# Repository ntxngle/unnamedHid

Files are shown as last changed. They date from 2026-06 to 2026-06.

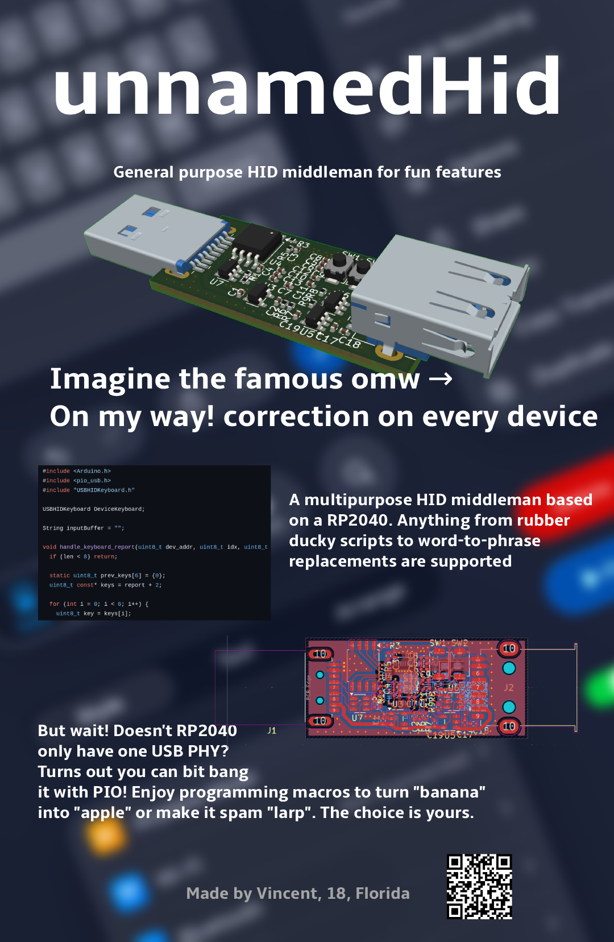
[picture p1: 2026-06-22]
docs/unzine.png

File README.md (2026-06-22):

# unnamedHid
## What and Why

A multipurpose HID middleman based on a RP2040. Anything from rubber ducky scripts to word-to-phrase replacements are supported.

After witnessing the beautiful mistakes (happy little accidents?) that Apple's autocorrect creates, I sought to implement the same on my computer.

Eventually I realized what I was making was in fact not autocorrect but a very small and versatile HID injector: thus bearing this project.

Disclaimer: This project is only for educational and legal purpose. Do not attempt to write malicious programs or keyloggers. I am not responsible for reproductions of this project being used with malintent.

## Tuff photos






## How it works

THe entire device is based on the RP2040 MCU. The built-in PHY connects to the host computer (important for USB programming), and the PIO bitbang interface is connected to the slave device.

The practice of using the PIO as a second USB PHY is not an original nor failproof idea. This approach, taken from Adafruit's own implementation on their Feather boards, probably won't get you the USB3.0 speeds, or even 2 reliably. However, for low speed keyboards and even mice, this approach works just fine.

## BOM
|name |footprint |board name |quantity|
|---|---|---|---|
|100nF |C_0402_1005Metric |C19,C8,C17,C11,C5,C6,C12,C9,C4,C7,C3|11 |
|1uF |C_0402_1005Metric |C2,C13,C1,C10 |4 |
|USBLC6-2SC6|SOT-23-6 |U6,U7 |2 |
|AP2112K-3.3|SOT-23-5 |U3 |1 |
|22uF |C_0402_1005Metric |C18 |1 |
|TPS2041B |SOT-23-5 |U5 |1 |
|USB_A |USB3_A_Receptacle_Wuerth_692122030100 |J2 |1 |
|R |R_0402_1005Metric |R2,R1 |2 |
|BOOT |SW_SPST_TS-1088-xR025 |SW1 |1 |
|1k |R_0402_1005Metric |R7,R3,R4 |3 |
|15k |R_0402_1005Metric |R9,R8 |2 |
|RUN |SW_SPST_TS-1088-xR025 |SW2 |1 |
|10k |R_0402_1005Metric |R6,R5 |2 |
|USB_A |USB3_A_Plug_Wuerth_692112030100_Horizontal|J1 |1 |
|W25Q32JVSS |SOIC-8_5.3x5.3mm_P1.27mm |U4 |1 |
|15pF |C_0402_1005Metric |C15,C16 |2 |
|ABM8-272-T3|Crystal_SMD_3225-4Pin_3.2x2.5mm |Y1 |1 |
|RP2040 |QFN-56-1EP_7x7mm_P0.4mm_EP3.2x3.2mm |U1 |1 |

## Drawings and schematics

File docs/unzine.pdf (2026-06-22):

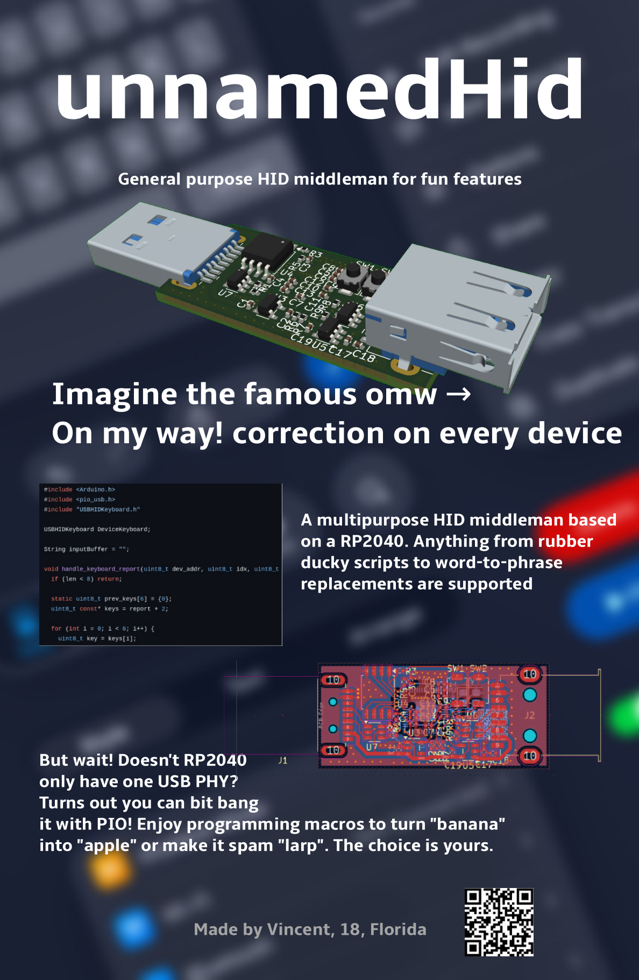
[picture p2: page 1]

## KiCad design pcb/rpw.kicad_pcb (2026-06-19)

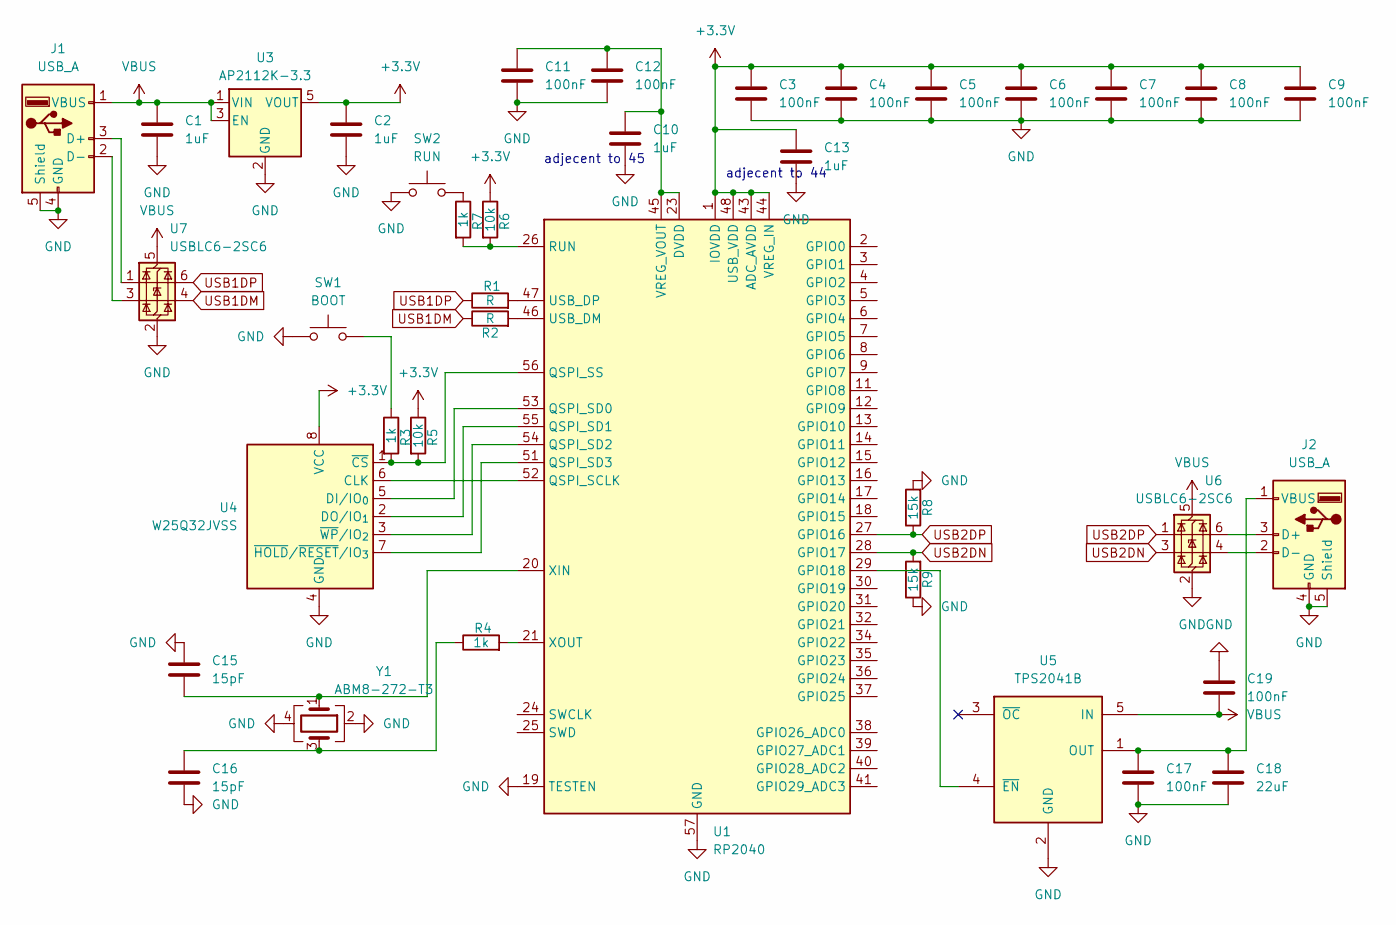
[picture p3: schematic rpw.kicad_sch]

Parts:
C1, C2, C10, C13: 1uF; C_0402_1005Metric
C3, C4, C5, C6, C7, C8, C9, C11, C12, C17, C19: 100nF; C_0402_1005Metric
C15, C16: 15pF; C_0402_1005Metric
C18: 22uF; C_0402_1005Metric
J1: USB_A; USB3_A_Plug_Wuerth_692112030100_Horizontal
J2: USB_A; USB3_A_Receptacle_Wuerth_692122030100
R1, R2: R; R_0402_1005Metric
R3, R4, R7: 1k; R_0402_1005Metric
R5, R6: 10k; R_0402_1005Metric
R8, R9: 15k; R_0402_1005Metric
SW1: BOOT; SW_SPST_TS-1088-xR025
SW2: RUN; SW_SPST_TS-1088-xR025
U1: RP2040; QFN-56-1EP_7x7mm_P0.4mm_EP3.2x3.2mm
U3: AP2112K-3.3; SOT-23-5
U4: W25Q32JVSS; SOIC-8_5.3x5.3mm_P1.27mm
U5: TPS2041B; SOT-23-5
U6, U7: USBLC6-2SC6; SOT-23-6
Y1: ABM8-272-T3; Crystal_SMD_3225-4Pin_3.2x2.5mm

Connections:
+3.3V: C2.1, C3.1, C4.1, C5.1, C6.1, C7.1, C8.1, C9.1, C13.1, R5.1, R6.1, U1.1 (IOVDD), U1.10 (IOVDD), U1.22 (IOVDD), U1.33 (IOVDD), U1.42 (IOVDD), U1.43 (ADC_AVDD), U1.44 (VREG_IN), U1.48 (USB_VDD), U1.49 (IOVDD), U3.5 (VOUT), U4.8 (VCC)
GND: C1.2, C2.2, C3.2, C4.2, C5.2, C6.2, C7.2, C8.2, C9.2, C10.2, C11.2, C12.2, C13.2, C15.1, C16.2, C17.2, C18.2, C19.1, J1.4 (GND), J1.5 (Shield), J2.4 (GND), J2.5 (Shield), R8.2, R9.1, SW1.1, SW2.1, U1.19 (TESTEN), U1.57 (GND), U3.2 (GND), U4.4 (GND), U5.2 (GND), U6.2 (GND), U7.2 (GND), Y1.2, Y1.4
unnamed: C16.1, R4.1, Y1.3
unnamed: J1.3 (D+), U7.1 (I/O1)
unnamed: J1.2 (D-), U7.3 (I/O2)
unnamed: J2.3 (D+), U6.6 (I/O1)
unnamed: J2.2 (D-), U6.4 (I/O2)
unnamed: C17.1, C18.1, J2.1 (VBUS), U5.1 (OUT)
unnamed: R3.1, SW1.2
unnamed: R7.1, SW2.2
unnamed: U1.29 (GPIO18), U5.4 (~EN)
unnamed: U1.52 (QSPI_SCLK), U4.6 (CLK)
unnamed: U1.53 (QSPI_SD0), U4.5 (DI/IO_{0})
unnamed: U1.55 (QSPI_SD1), U4.2 (DO/IO_{1})
unnamed: U1.54 (QSPI_SD2), U4.3 (~WP/IO_{2})
unnamed: U1.51 (QSPI_SD3), U4.7 (~HOLD/~RESET/IO_{3})
unnamed: R3.2, R5.2, U1.56 (QSPI_SS), U4.1 (~CS)
unnamed: R6.2, R7.2, U1.26 (RUN)
unnamed: R2.2, U1.46 (USB_DM)
unnamed: R1.2, U1.47 (USB_DP)
unnamed: C10.1, C11.1, C12.1, U1.23 (DVDD), U1.45 (VREG_VOUT), U1.50 (DVDD)
unnamed: C15.2, U1.20 (XIN), Y1.1
unnamed: R4.2, U1.21 (XOUT)
USB1DM: R2.1, U7.4 (I/O2)
USB1DP: R1.1, U7.6 (I/O1)
USB2DN: R9.2, U1.28 (GPIO17), U6.3 (I/O2)
USB2DP: R8.1, U1.27 (GPIO16), U6.1 (I/O1)
VBUS: C1.1, C19.2, J1.1 (VBUS), U3.1 (VIN), U3.3 (EN), U5.5 (IN), U6.5 (VBUS), U7.5 (VBUS)

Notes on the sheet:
adjecent to 44
adjecent to 45

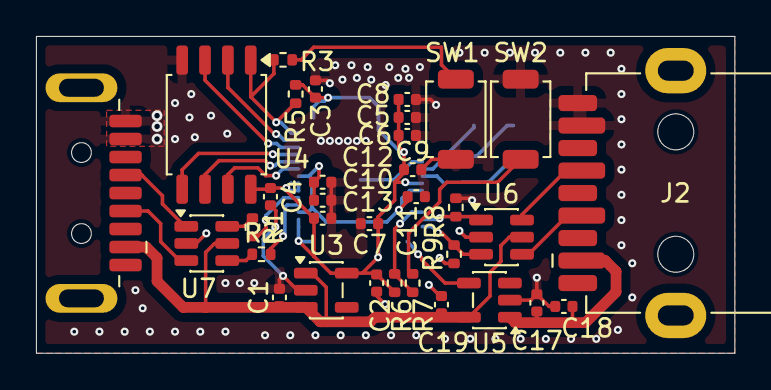
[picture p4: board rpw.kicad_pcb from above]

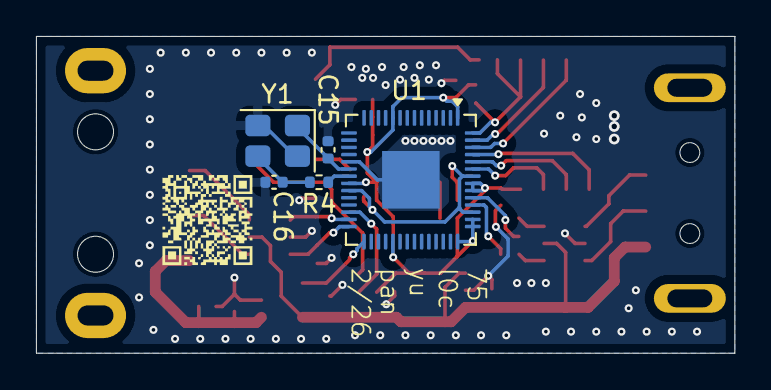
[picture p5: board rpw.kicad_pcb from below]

Board: 2 copper layers, 38.8 x 17.6 mm, 38 parts (5 on the bottom side), 28 nets.

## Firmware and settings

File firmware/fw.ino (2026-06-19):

#include <Arduino.h>
#include <pio_usb.h>
#include "USBHIDKeyboard.h"

USBHIDKeyboard DeviceKeyboard;

String inputBuffer = "";

void handle_keyboard_report(uint8_t dev_addr, uint8_t idx, uint8_t const* report, uint16_t len) {
  if (len < 8) return;

  static uint8_t prev_keys[6] = {0};
  uint8_t const* keys = report + 2;

  for (int i = 0; i < 6; i++) {
    uint8_t key = keys[i];
    if (key == 0) continue;

    bool already_pressed = false;
    for (int j = 0; j < 6; j++) {
      if (key == prev_keys[j]) {
        already_pressed = true;
        break;
      }
    }

    if (!already_pressed) {
      char c = 0;
      if (key >= 4 && key <= 29) {
        c = 'a' + (key - 4);
      }

      if (c != 0) {
        inputBuffer += c;
        if (inputBuffer.length() > 6) {
          inputBuffer.remove(0, 1);
        }

        if (inputBuffer == "banana") {
          
          delay(50); 
          
          for (int b = 0; b < 6; b++) {
            DeviceKeyboard.press(KEY_BACKSPACE);
            DeviceKeyboard.releaseAll();
            delay(10);
          }

          DeviceKeyboard.print("apple");
          
          inputBuffer = "";
        }
      }
    }
  }

  memcpy(prev_keys, keys, 6);
}

static void pio_usb_configuration() {
  static pio_usb_configuration_t config = PIO_USB_DEFAULT_CONFIG;
  config.pin_dp = 16; 
  
  USBHost.begin(&config);
}

void setup() {
  
  DeviceKeyboard.begin();
  
  pio_usb_configuration();
  
}

void loop() {
  USBHost.task();
}

void setup1() {}
void loop1() {
  USBHost.task();
}
